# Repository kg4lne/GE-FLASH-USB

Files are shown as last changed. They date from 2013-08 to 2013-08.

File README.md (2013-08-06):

GE-Flash-USB X2212/X2444 EPROM Programmer
=========================================

This archive contains all the CAD and firmware files necessary to build the
GE-Flash-USB EPROM programmer for use with the GE-Flash programming software
by KG4LNE. GE-Flash is a complete solution for programming vintage GE Phoenix,
Delta and Ranger VHF/UHF commercial radios. For more information, please visit
the website at http://www.rtzaudio.com/kg4lne for additional information.

This package includes all PCB CAD files and firmware C source code. All PCB CAD
files are in Cadsoft Eagle v6.4.0 format. The source code for the AT90USB firmware
was developed in Atmel Studio 6.1 and was originally adapted from the USBKEY sample
provided by Atmel. I modified this from a mass storage device into to a simple
read/write USB device. The simple USB device can be accessed on Windows 7/8 via
the built-in generic WinUSB interface that ships with Windows.

You will need to install and configure your GE-Flash-USB programmer device to
communicate with WinUSB just like any other device though. The GE-Flash-USB driver
install and INF files are located on my website and are included in the 
GE-Flash application installer also. Be sure and have the INF and other driver
files on your machine (or install the GE-Flash application first). You can let
Windows search the GE-Flash program files application directory for the INF
file as well.

Note the BOM files for the programmer PCB are located in the project BOM 
subdirectory, here you'll also find an order upload file
"GEF-USB-B_OrderUploadDigiKey.csv" that can be uploaded to Digikey.
Upload the parts order file using the Digikey BOM manager in your account,
this will preload an order with all parts needed to build the PCB. 

Enjoy!

KG4LNE

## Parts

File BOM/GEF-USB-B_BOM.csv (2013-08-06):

Qty | Part References | Value | Package | Mfg Part Num | Mfg Name | VID | Vendor Part Num | Description | XREF
9 | C2, C10, C11, C50, C51, C52, C55, C56, C57 | 0.1uF | C0805 | GCM21BR72A104KA37L | Murata Electronics | DK | 490-4789-1-ND | CAP CER .1UF 100V X7R 0805 | REF24
3 | C9(DNP), C14, C15 | 0.22uF | C0805 | GCM21BR71H224KA37L | Murata Electronics | DK | 490-4970-1-ND | CAP CER .22UF 50V X7R 0805 | REF26
1 | R50 | 0R | R0805 | ERJ-6GEY0R00V | Panasonic - ECG | DK | P0.0ACT-ND | RES 0.0 OHM 1/8W 0805 SMD | REF29
4 | R2, R7, R8, R14 | 1K | R0805 | ERJ-6ENF1001V | Panasonic - ECG | DK | P1.00KCCT-ND | RES 1.00K OHM 1/8W 1% 0805 SMD | REF30
7 | C3, C4, C5, C6, C8, C53, C54 | 1uF | C0805 | GCM21BR71E105KA56L | Murata Electronics | DK | 490-4785-1-ND | CAP CER 1UF 25V X7R 0805 | REF27
1 | R1 | 3.40K | R0805 | ERJ-6ENF3401V | Panasonic - ECG | DK | P3.40KCCT-ND | RES 3.40K OHM 1/8W 1% 0805 SMD | REF31
1 | C7 | 4.7uF | C3528/T | TAJB475K010RNJ | AVX Corporation | DK | 478-3886-1-ND | CAP TANTALUM 4.7UF 10V 10% SMD | REF23
1 | C1 | 4.7uF | C7343/T | TAJD475M035RNJ | AVX Corporation | DK | 478-3934-1-ND | CAP TANTALUM 4.7UF 35V 20% SMD | REF22
1 | Y1 | 8.0 MHZ | HC49UP | ECS-80-18-5PX-TR | ECS Inc | DK | XC1271CT-ND | CRYSTAL 8.00MHZ 18PF SMD | REF17
3 | R3, R6, R51 | 10K | R0805 | ERJ-6ENF1022V | Panasonic - ECG | DK | P10.2KCCT-ND | RES 10.2K OHM 1/8W 1% 0805 SMD | REF32
2 | R10, R11 | 22R | R0805 | ERJ-6ENF22R1V | Panasonic - ECG | DK | P22.1CCT-ND | RES 22.1 OHM 1/8W 1% 0805 SMD | REF33
2 | C12, C13 | 22pF | C0805 | GRM2195C2A220JZ01D | Murata Electronics | DK | 490-1591-1-ND | CAP CER 22PF 100V 5% C0G 0805 | REF25
3 | R4(DNP), R12, R13 | 47K | R0805 | ERJ-6ENF4702V | Panasonic - ECG | DK | P47.0KCCT-ND | RES 47.0K OHM 1/8W 1% 0805 SMD | REF35
2 | RN1, RN2 | 47R | 744-8 | 744C083470JTR | CTS Resistor Products | DK | 744C083470JPCT-ND | RES ARRAY 47 OHM 8TERM 4RES SMD | REF20
1 | RN50 | 100K | 744-8 | 744C083104JPTR | CTS Resistor Products | DK | 744C083104JPCT-ND | RES ARRAY 100KOHM 8TERM 4RES SMD | REF21
2 | R5, R9 | 100K | R0805 | ERJ-6ENF1003V | Panasonic - ECG | DK | P100KCCT-ND | RES 100K OHM 1/8W 1% 0805 SMD | REF36
1 | BOM-PART1 | 151IBK | * | 151IBK | Serpac | DK | SR151-IB-ND | PLASTIC ENCLOSURE 5.62X3.25X1.50 BLACK | REF39
1 | J3 | 182-009-113R531 | NC182M9 | 182-009-113R531 | Norcomp Inc. | DK | 182-09ME-ND | CONN DB9 MALE .318 R/A NICKEL | REF15
1 | BOM-PART2 | 801-93-050-10-001000 | * | 801-93-050-10-001000 | Mill-Max Mfg Corp | DK | ED7150-ND | SIP SOCKET 50 POS STRAIGHT PCB | REF40
1 | J4 | 56579-0576 | 56579-0576 | 56579-0576 | Molex Inc | DK | WM17122CT-ND | CONN RECEPT USB 5POS RT ANG SMD | REF14
1 | JP1 | 961204-6404-AR | JP2Q | 961204-6404-AR | 3M | DK | 3M9458-ND | CONN HEADER VERT DUAL 4POS GOLD | REF42
1 | J2 | 961206-6404-AR | HDR-MA03-2 | 961206-6404-AR | 3M | DK | 3M9459-ND | CONN HEADER VERT DUAL 6POS GOLD | REF43
1 | J5 | 5103309-1 | HDR-5103309-1 | 5103309-1 | Tyco Electronics | DK | A33160-ND | CONN HEADER LOPRO STR 10POS GOLD | REF16
1 | U3 | AT90USB1286-AU | TQFP64A | AT90USB1286-AU | Atmel | DK | AT90USB1286-AURCT-ND | MCU AVR 64K FLASH 16MHZ 64TQFP | REF2
1 | S50(DNP) | B3F-1025 | B3F-10XX-B | B3F-1025 | Omron Electronics Inc | DK | SW794-ND | SWITCH TACT 6MM 260GF H=5.0MM | REF11
2 | S1, S2 | B3U-1000P | B3U-1000P | B3U-1000P | Omron Electronics Inc | DK | SW1020CT-ND | SWITCH TACT SPST W/O GND SMD | REF12
2 | D1, D2 | B140-13-F | SMA | B140-13-F | Diodes Inc | DK | B140-FDICT-ND | DIODE SCHOTTKY 40V 1A SMA | REF38
2 | Q2, Q4 | BC847BMTF | SOT23 | BC847BMTF | Fairchild Semiconductor | DK | BC847BMTFCT-ND | TRANSISTOR NPN 45V 0.1A SOT23 | REF4
1 | L50 | BEAD | L0805 | BLM21PG221SN1D | Murata Electronics | DK | 490-1054-1-ND | FERRITE CHIP 220 OHM 2000MA 0805 | REF28
1 | B1 | DF005S | DF-S | DF005S | Fairchild Semiconductor | DK | DF005SCT-ND | DIODE BRIDGE 50V 1.5A 4-SDIP | REF5
2 | Q1, Q3 | DMP3130L | SOT23 | DMP3130L | Diodes Inc | DK | DMP3130LDICT-ND | MOSFET P-CH 30V 3.5A SOT-23 | REF6
2 | D50, D53 | GREEN | LED3MM | TLHG4405 | Vishay Semiconductor | DK | 751-1101-ND | LED 3MM GREEN 15MCD GAP ON GAP | REF10
1 | U1 | LM340MP-5.0/NOPB | SOT223 | LM340MP-5.0/NOPB | National Semiconductor | DK | LM340MP-5.0/NOPBCT-ND | IC REG LDO 5V 1A SOT223 | REF7
1 | U2 | MAX232ECWE | SO16W | MAX232ECWE+ | Maxim Integrated Products | DK | MAX232ECWE+-ND | IC TXRX RS232 5V ESD-PROT 16SOIC | REF8
1 | F1 | MINISMDC014F-2 | F1812 | MINISMDC014F-2 | Tyco Electronics | DK | MINISMDC014FCT-ND | POLYSWITCH .14A RESET FUSE SMD | REF19
2 | D51, D52 | PGB1010603MR | PGB-0603 | PGB1010603MR | Littelfuse Inc | DK | F2594CT-ND | SUPPRESSOR ESD 24VDC 0603 SMD | REF18
1 | J1 | PJ-102AH/BH | PJ-102XH | PJ-102AH | CUI Inc | DK | CP-102AH-ND | CONN PWR JACK 2.1X5.5MM HIGH CUR | REF13
1 | D54 | RED | LED3MM | TLHR4405 | Vishay Semiconductor | DK | 751-1129-ND | LED 3MM RED 15MCD GAASP ON GAP | REF9
1 | X50 | ZIF28 | ZIF28 | 28-6554-11 | Aries Electronics | DK | A303-ND | 28 PIN ZIF SOCKET GOLD | REF41

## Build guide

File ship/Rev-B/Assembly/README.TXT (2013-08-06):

This directory contains files needed for pick/place assembly and manufacturing.

GEF-USB-B		06/18/2013

GEF-USB-B.cad		GenCad Mount Data
GEF-USB-B.fab		Fabmaster Data
GEF-USB-B.mnt		Generic format Mount X/Y Data
GEF-USB-B.ict		In circuit test net data for electical testing
GEF-USB-B-Top.pdf	PDF top side silk screen image
GEF-USB-B-Bot.pdf	PDF bottom side silk screen image

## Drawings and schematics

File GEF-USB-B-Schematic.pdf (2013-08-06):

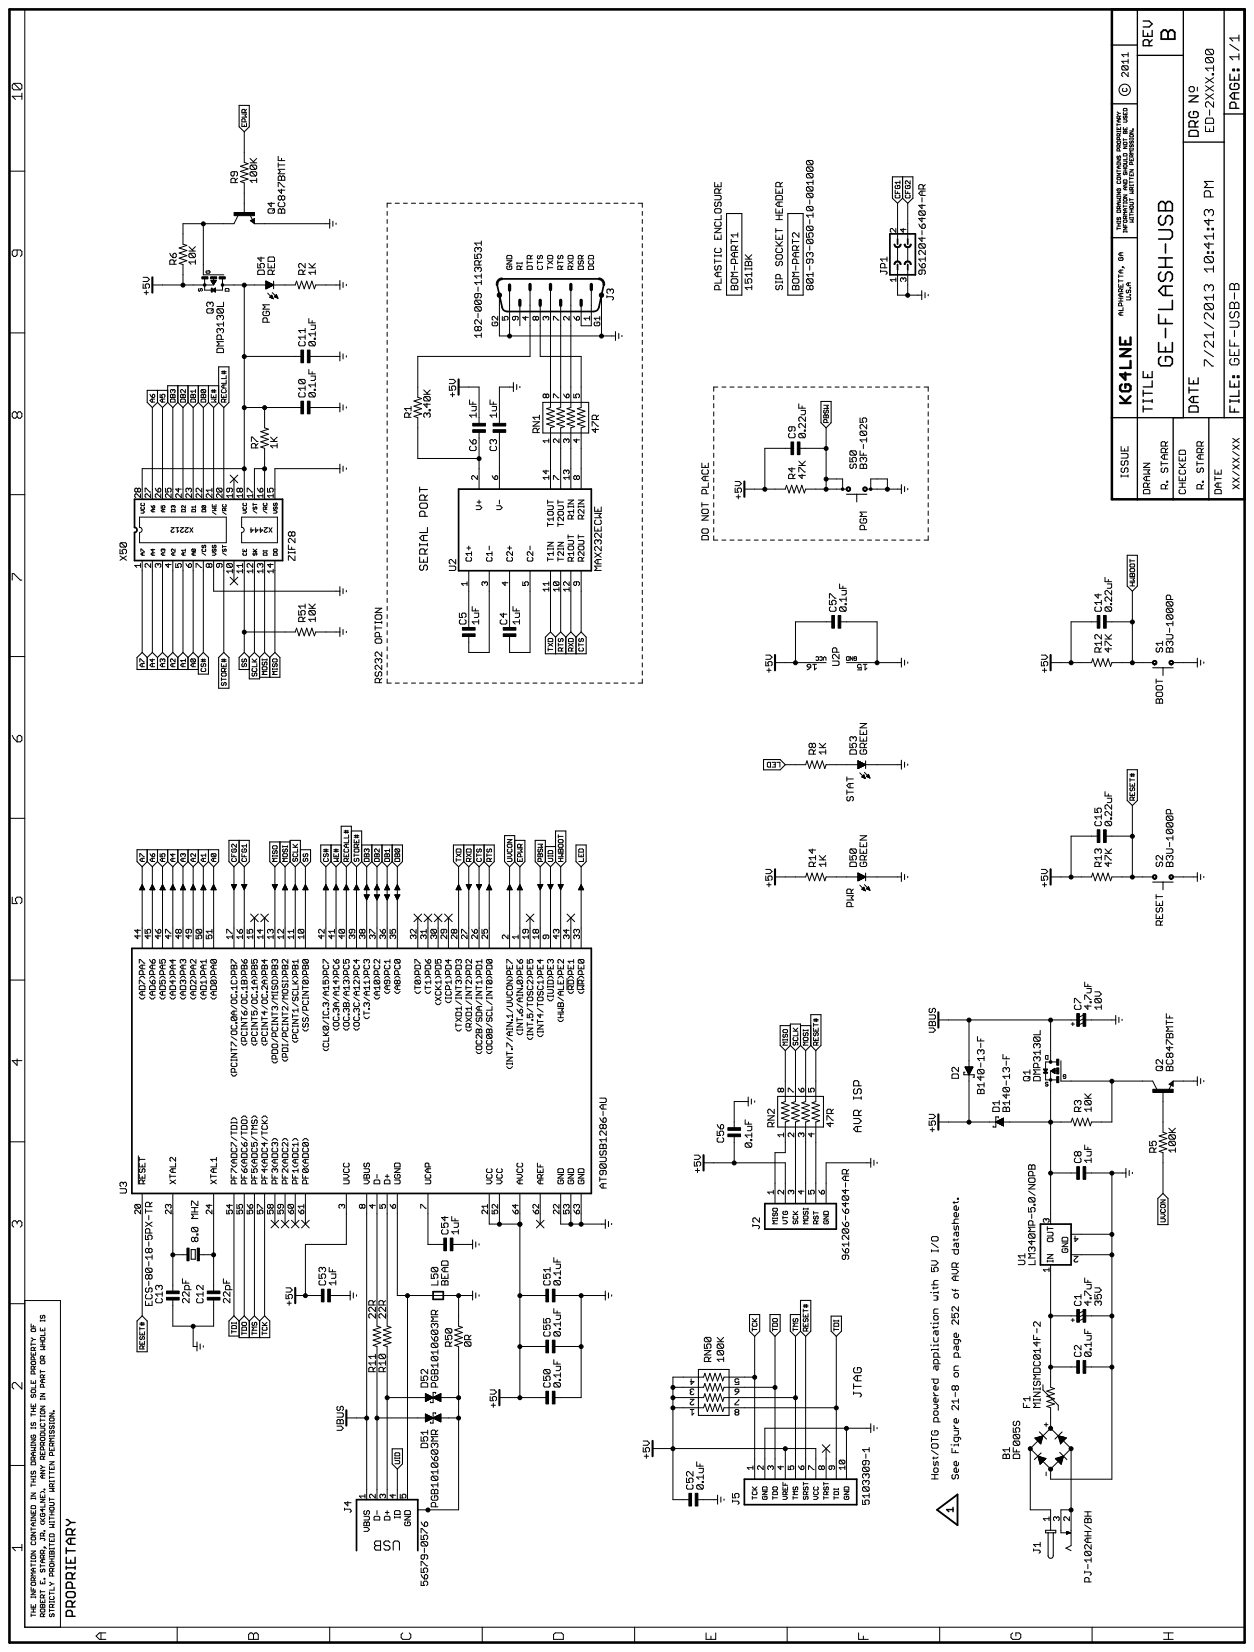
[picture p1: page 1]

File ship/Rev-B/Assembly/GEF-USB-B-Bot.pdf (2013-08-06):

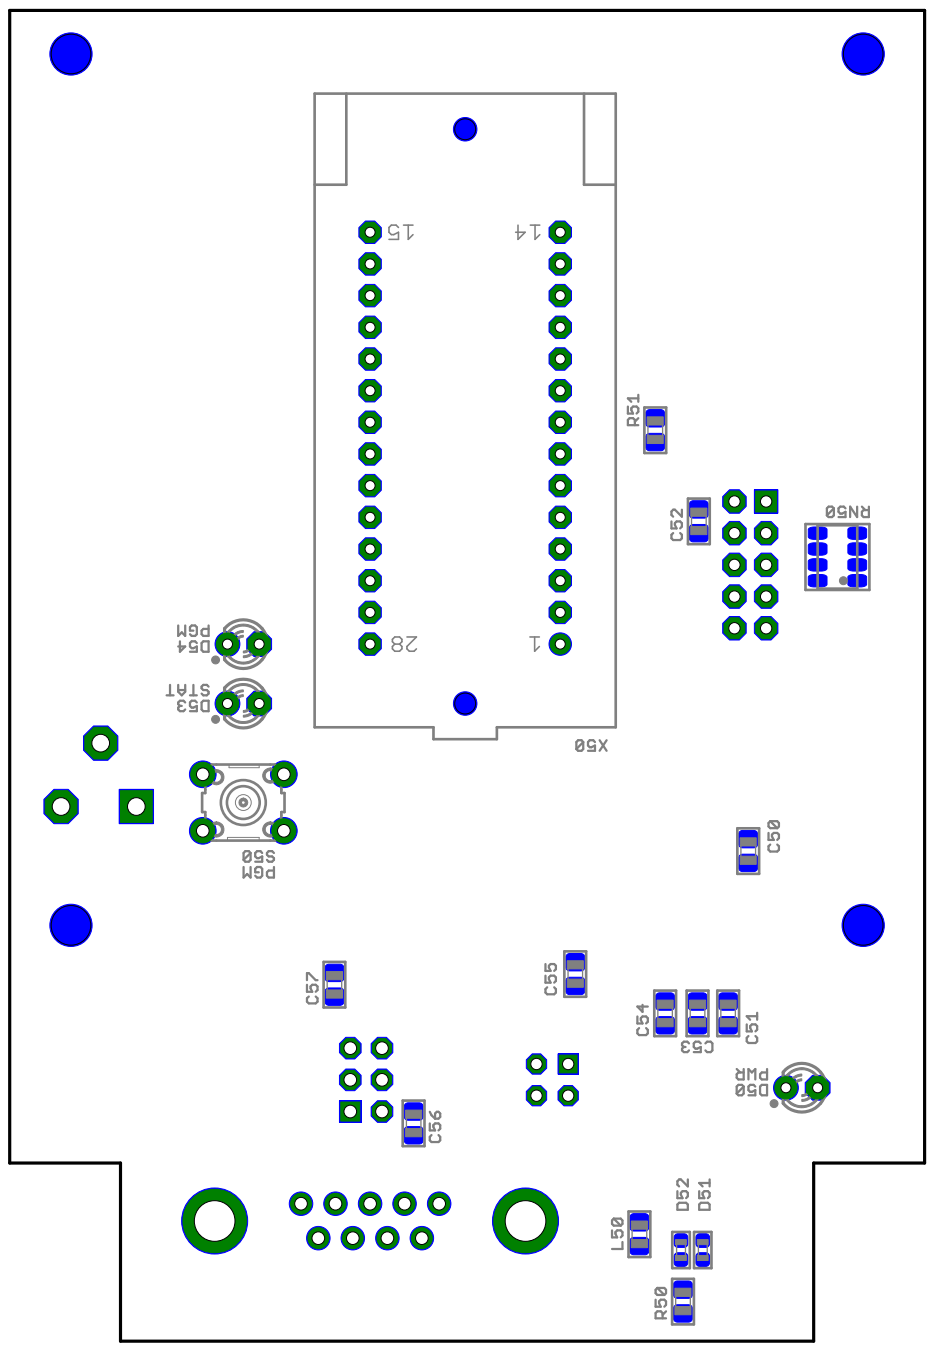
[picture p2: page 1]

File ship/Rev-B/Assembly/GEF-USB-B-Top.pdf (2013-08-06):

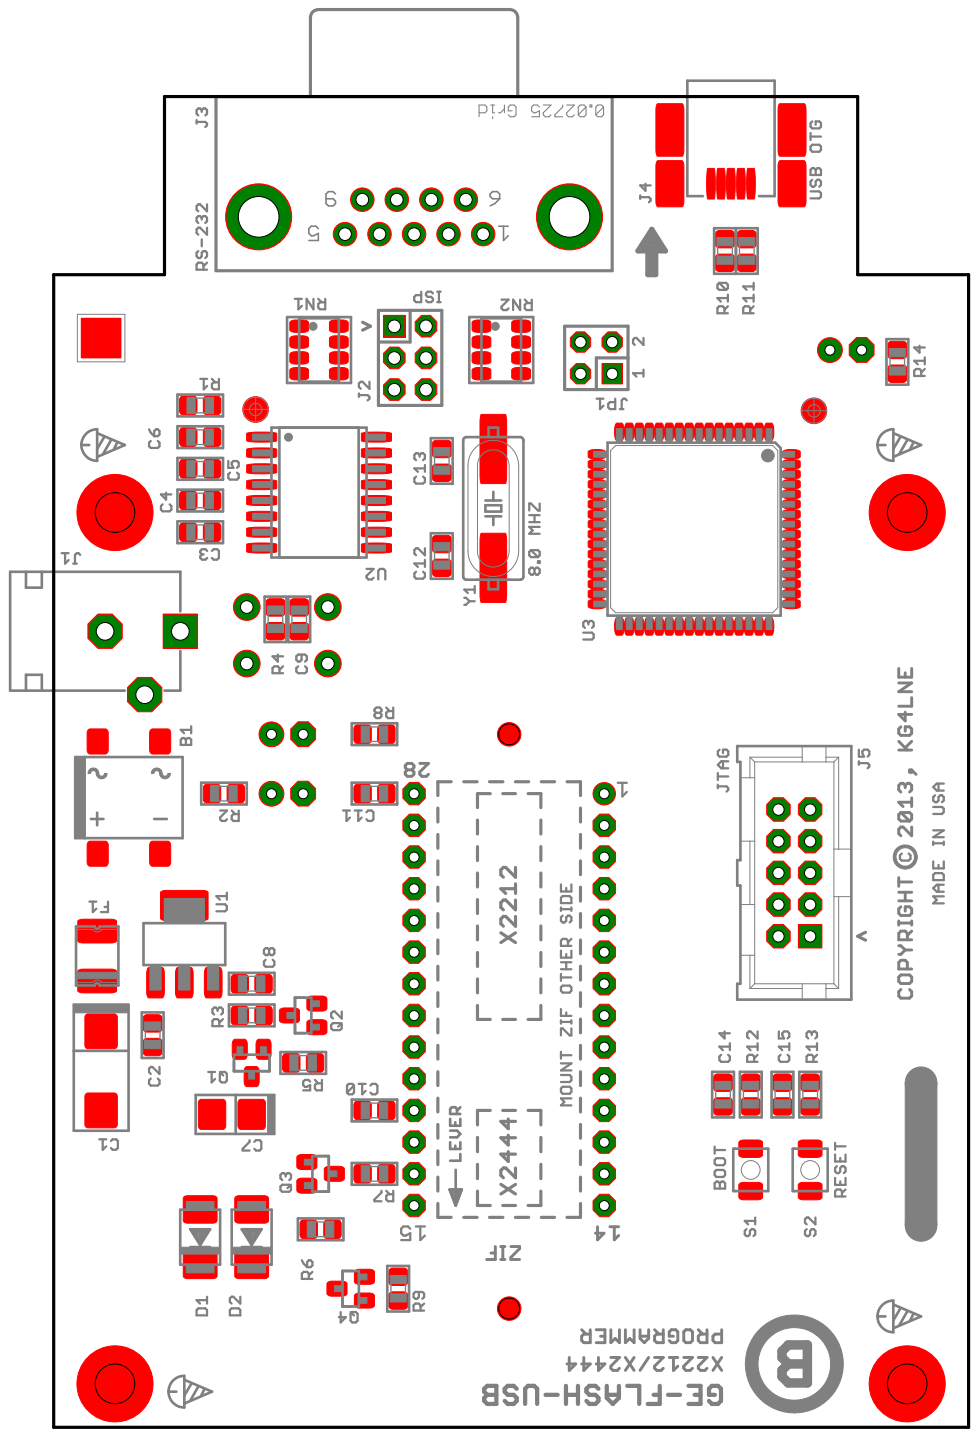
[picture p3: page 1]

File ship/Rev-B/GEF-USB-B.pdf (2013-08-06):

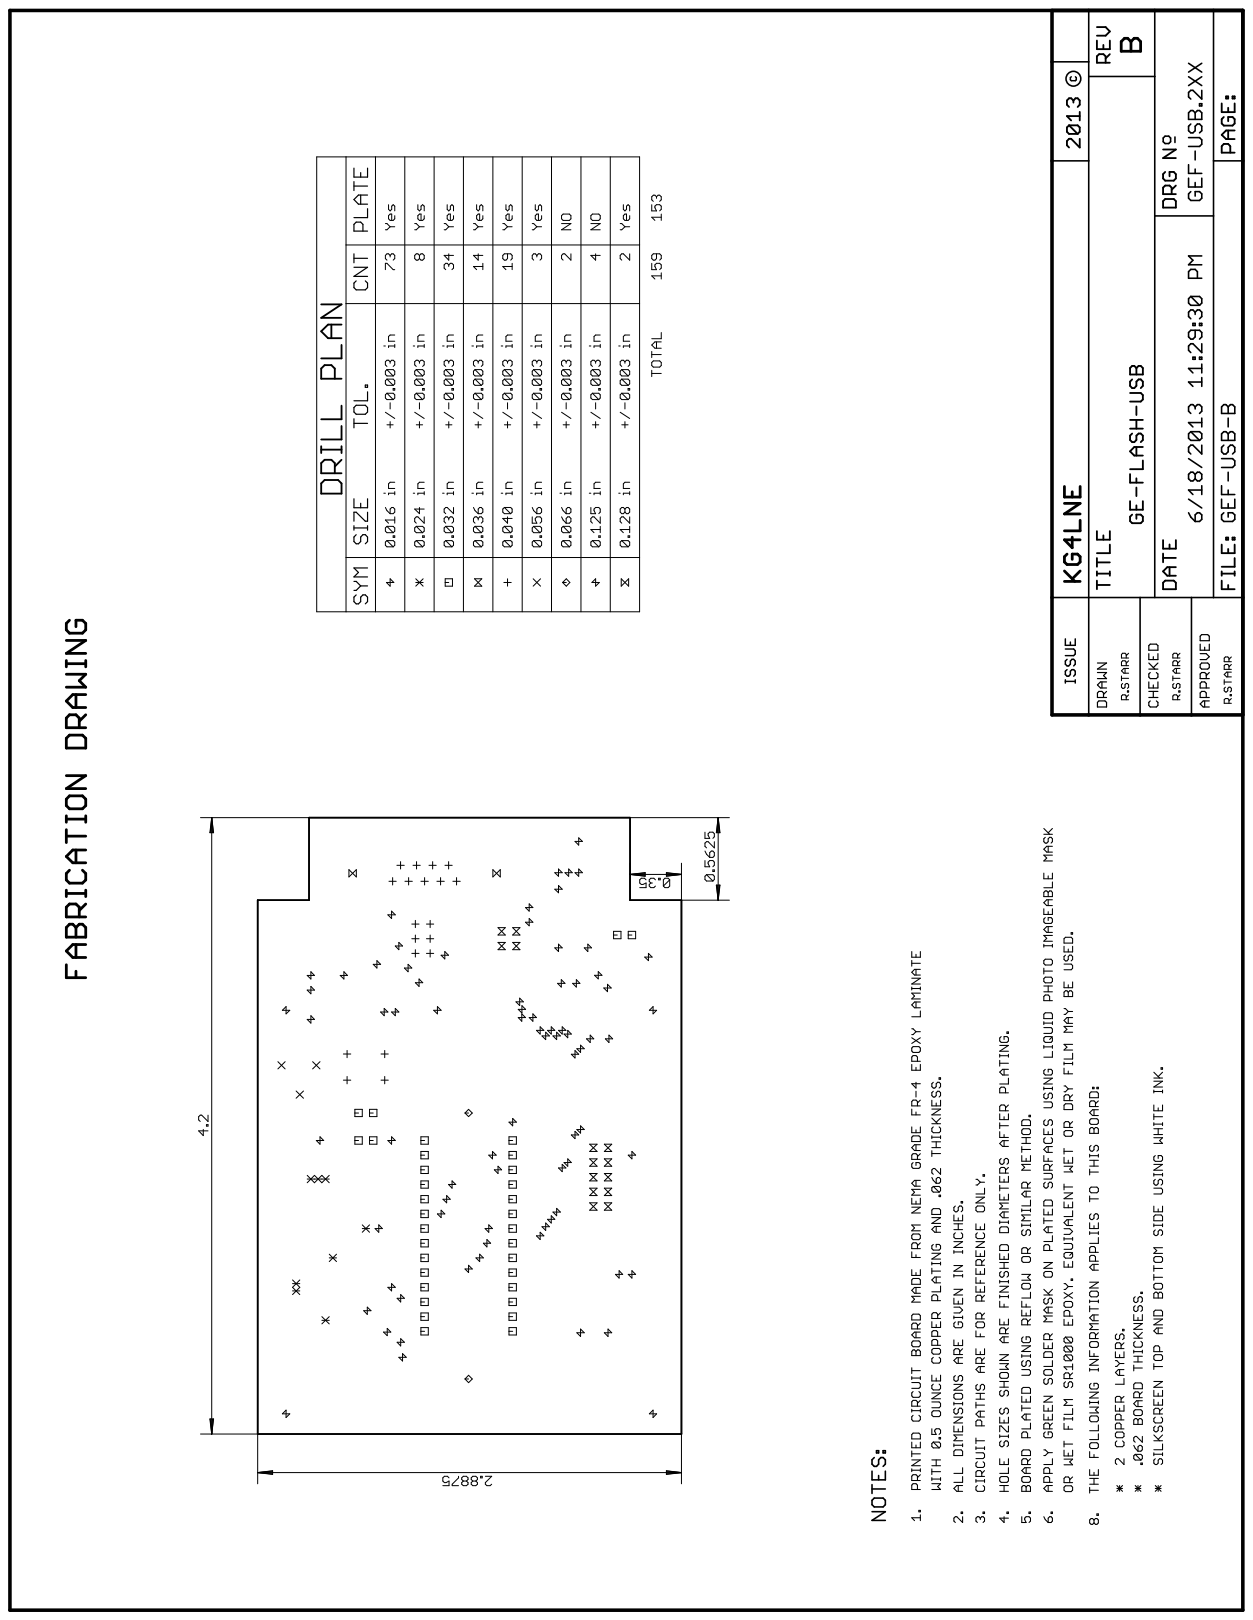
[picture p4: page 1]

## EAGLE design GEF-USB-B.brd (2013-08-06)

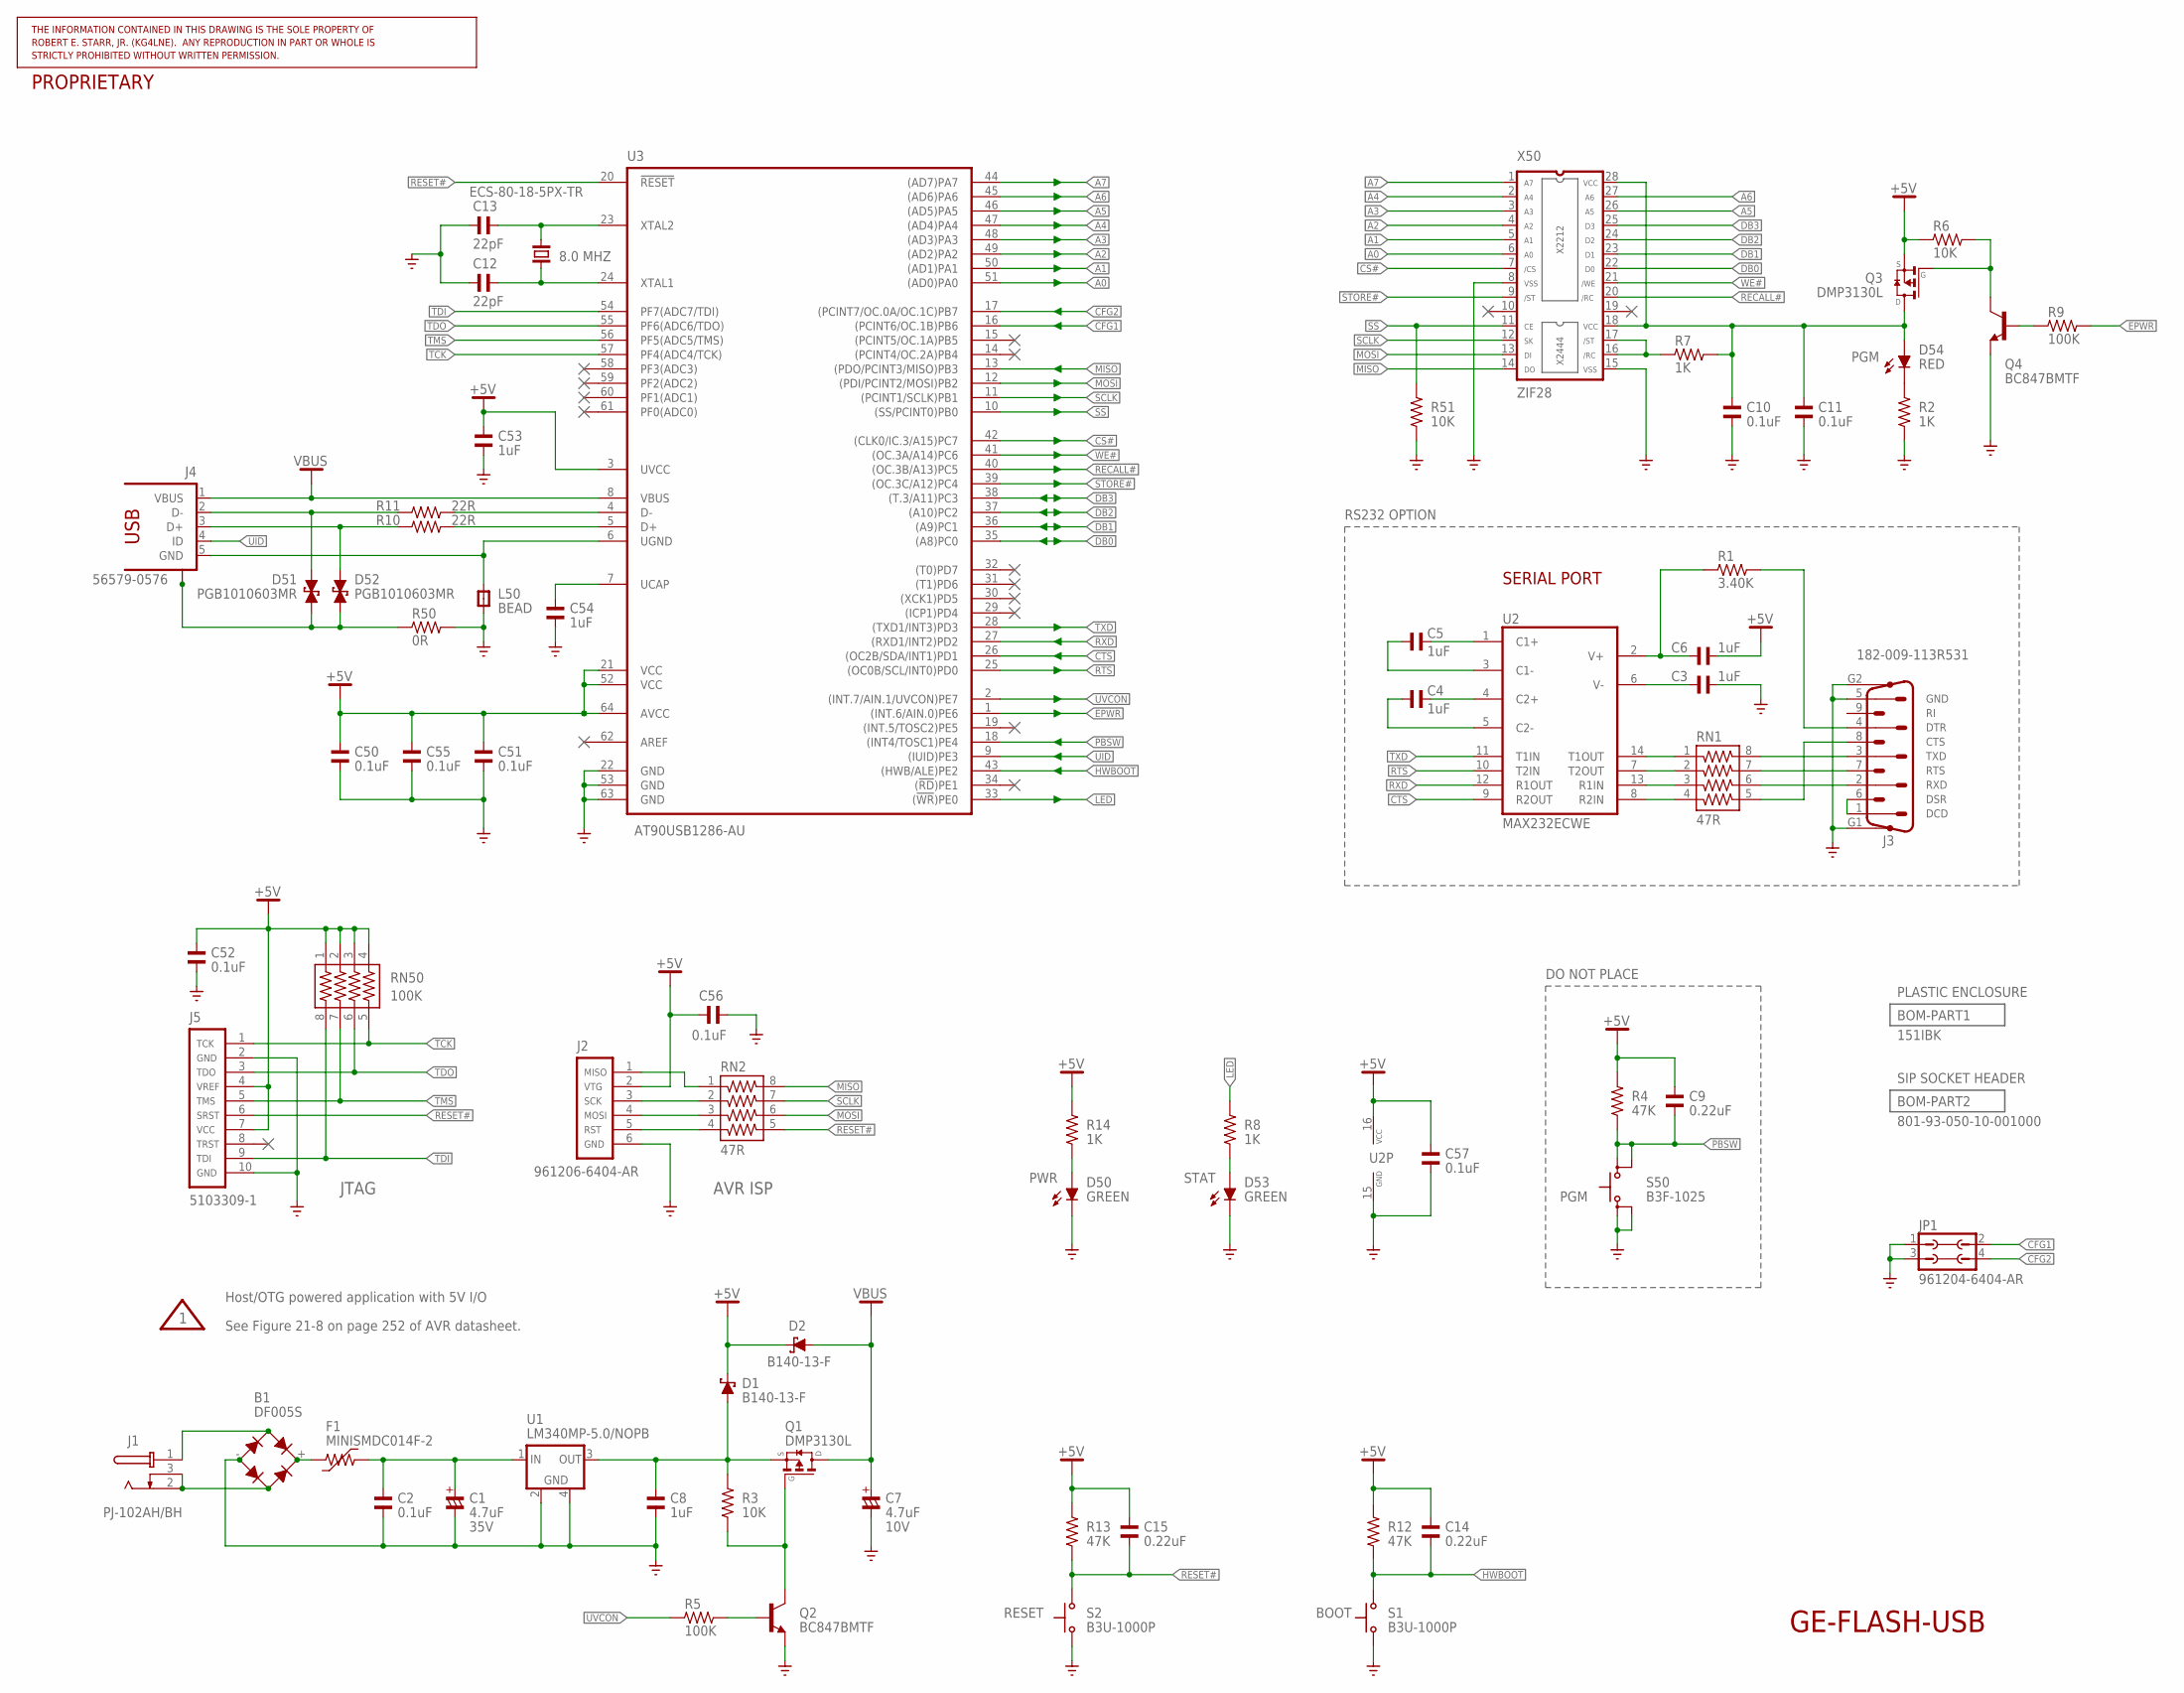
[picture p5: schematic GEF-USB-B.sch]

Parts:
B1: DF005S; DF-S; PARTNO DF005S
C1: 4.7uF; C7343/T; PARTNO TAJD475M035RNJ
C2, C10, C11, C50, C51, C52, C55, C56, C57: 0.1uF; C0805; PARTNO GCM21BR72A104KA37L
C3, C4, C5, C6, C8, C53, C54: 1uF; C0805; PARTNO GCM21BR71E105KA56L
C7: 4.7uF; C3528/T; PARTNO TAJB475K010RNJ
C9, C14, C15: 0.22uF; C0805; PARTNO GCM21BR71H224KA37L
C12, C13: 22pF; C0805; PARTNO GRM2195C2A220JZ01D
D1, D2: B140-13-F; SMA; PARTNO B140-13-F
D50, D53: GREEN; LED3MM; PARTNO TLHG4405
D51, D52: PGB1010603MR; PGB-0603; PARTNO PGB1010603MR
D54: RED; LED3MM; PARTNO TLHR4405
F1: MINISMDC014F-2; F1812; PARTNO MINISMDC014F-2
J1: PJ-102AH/BH; PJ-102XH; PARTNO PJ-102AH
J2: 961206-6404-AR; HDR-MA03-2; PARTNO 961206-6404-AR
J3: 182-009-113R531; NC182M9; PARTNO 182-009-113R531
J4: 56579-0576; PARTNO 56579-0576
J5: 5103309-1; HDR-5103309-1; PARTNO 5103309-1
JP1: 961204-6404-AR; JP2Q; PARTNO 961204-6404-AR
L50: BEAD; L0805; PARTNO BLM21PG221SN1D
Q1, Q3: DMP3130L; SOT23; PARTNO DMP3130L
Q2, Q4: BC847BMTF; SOT23; PARTNO BC847BMTF
R1: 3.40K; R0805; PARTNO ERJ-6ENF3401V
R2, R7, R8, R14: 1K; R0805; PARTNO ERJ-6ENF1001V
R3, R6, R51: 10K; R0805; PARTNO ERJ-6ENF1022V
R4, R12, R13: 47K; R0805; PARTNO ERJ-6ENF4702V
R5, R9: 100K; R0805; PARTNO ERJ-6ENF1003V
R10, R11: 22R; R0805; PARTNO ERJ-6ENF22R1V
R50: 0R; R0805; PARTNO ERJ-6GEY0R00V
RN1, RN2: 47R; 744-8; PARTNO 744C083470JTR
RN50: 100K; 744-8; PARTNO 744C083104JPTR
S1, S2: B3U-1000P; PARTNO B3U-1000P
S50: B3F-1025; B3F-10XX-B; PARTNO B3F-1025
U1: LM340MP-5.0/NOPB; SOT223; PARTNO LM340MP-5.0/NOPB
U2: MAX232ECWE; SO16W; PARTNO MAX232ECWE+
U3: AT90USB1286-AU; TQFP64A; PARTNO AT90USB1286-AU
X50: ZIF28; PARTNO 28-6554-11
Y1: 8.0 MHZ; HC49UP; PARTNO ECS-80-18-5PX-TR

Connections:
+5V: C6.1, C9.2, C14.2, C15.2, C50.1, C51.2, C52.1, C53.2, C55.1, C56.2, C57.1, D1.C, D2.C, J2.2, J5.4, J5.7, Q3.2 (S), R4.2, R6.1, R12.2, R13.2, R14.2, RN50.1, RN50.2, RN50.3, RN50.4, U2.16 (VCC), U3.3 (UVCC), U3.21 (VCC), U3.52 (VCC), U3.64 (AVCC)
A0: U3.51 ((AD0)PA0), X50.6
A1: U3.50 ((AD1)PA1), X50.5
A2: U3.49 ((AD2)PA2), X50.4
A3: U3.48 ((AD3)PA3), X50.3
A4: U3.47 ((AD4)PA4), X50.2
A5: U3.46 ((AD5)PA5), X50.26
A6: U3.45 ((AD6)PA6), X50.27
A7: U3.44 ((AD7)PA7), X50.1
CFG1: JP1.2, U3.16 ((PCINT6/OC.1B)PB6)
CFG2: JP1.4, U3.17 ((PCINT7/OC.0A/OC.1C)PB7)
CS#: U3.42 ((CLK0/IC.3/A15)PC7), X50.7
CTS: U2.9 (R2OUT), U3.26 ((OC2B/SDA/INT1)PD1)
DB0: U3.35 ((A8)PC0), X50.22
DB1: U3.36 ((A9)PC1), X50.23
DB2: U3.37 ((A10)PC2), X50.24
DB3: U3.38 ((T.3/A11)PC3), X50.25
EPWR: R9.2, U3.1 ((INT.6/AIN.0)PE6)
GND: B1.-, C1.-, C2.1, C3.1, C7.-, C8.2, C10.1, C11.1, C12.1, C13.1, C50.2, C51.1, C52.2, C53.1, C54.1, C55.2, C56.1, C57.2, D50.K (C), D53.K (C), J2.6, J3.5, J3.G1, J3.G2, J5.2, J5.10, JP1.1, JP1.3, L50.1, Q2.2 (E), Q4.2 (E), R2.1, R50.2, R51.1, S1.1, S2.1, S50.3, S50.4 (P1), U1.2 (GND), U1.4 (GND1), U2.15 (GND), U3.22 (GND), U3.53 (GND), U3.63 (GND), X50.8, X50.15
HWBOOT: C14.1, R12.1, S1.2 (S), U3.43 ((HWB/ALE)PE2)
LED: R8.2, U3.33 ((!WR!)PE0)
MISO: RN2.8, U3.13 ((PDO/PCINT3/MISO)PB3), X50.14
MOSI: RN2.6, U3.12 ((PDI/PCINT2/MOSI)PB2), X50.13
unnamed: J2.5, RN2.4
unnamed: B1.AC2 (A2), J1.2 (S), J1.3 (SS)
unnamed: R10.2, U3.5 (D+)
unnamed: D52.2, J4.3 (D+), R10.1
unnamed: R11.2, U3.4 (D-)
unnamed: D51.2, J4.2 (D-), R11.1
unnamed: C54.2, U3.7 (UCAP)
unnamed: D50.A, R14.1
unnamed: D51.1, D52.1, J4.S1, J4.S2, J4.S3, J4.S4, R50.1
unnamed: D53.A, R8.1
unnamed: Q1.1 (G), Q2.3 (C), R3.1
unnamed: Q2.1 (B), R5.2
unnamed: Q3.1 (G), Q4.3 (C), R6.2
unnamed: C10.2, C11.2, D54.A, Q3.3 (D), R7.2, X50.18, X50.28
unnamed: D54.K (C), R2.2
unnamed: J4.5 (GND), L50.2, U3.6 (UGND)
unnamed: J3.1, J3.6
unnamed: C1.+, C2.2, F1.2, U1.1 (IN)
unnamed: C8.1, D1.A, Q1.2 (S), R3.2, U1.3 (OUT)
unnamed: J3.2, RN1.6
unnamed: B1.+, F1.1
unnamed: B1.AC1 (A1), J1.1 (T)
unnamed: Q4.1 (B), R9.1
unnamed: C12.2, U3.24 (XTAL1), Y1.1
unnamed: J3.7, RN1.7
unnamed: C3.2, U2.6 (V-)
unnamed: C6.2, R1.1, U2.2 (V+)
unnamed: C13.2, U3.23 (XTAL2), Y1.2
unnamed: C4.1, U2.4 (C2+)
unnamed: C5.1, U2.1 (C1+)
unnamed: C4.2, U2.5 (C2-)
unnamed: C5.2, U2.3 (C1-)
unnamed: J3.8, RN1.5
unnamed: J3.3, RN1.8
unnamed: RN1.3, U2.13 (R1IN)
unnamed: RN1.1, U2.14 (T1OUT)
unnamed: RN1.4, U2.8 (R2IN)
unnamed: J3.4, R1.2
unnamed: RN1.2, U2.7 (T2OUT)
unnamed: J2.1, RN2.1
unnamed: J2.3, RN2.2
unnamed: J2.4, RN2.3
PBSW: C9.1, R4.1, S50.1 (S), S50.2 (S1), U3.18 ((INT4/TOSC1)PE4)
PU2: R7.1, X50.16, X50.17
RECALL#: U3.40 ((OC.3B/A13)PC5), X50.20
RESET#: C15.1, J5.6, R13.1, RN2.5, S2.2 (S), U3.20 (!RESET!)
RTS: U2.10 (T2IN), U3.25 ((OC0B/SCL/INT0)PD0)
RXD: U2.12 (R1OUT), U3.27 ((RXD1/INT2)PD2)
SCLK: RN2.7, U3.11 ((PCINT1/SCLK)PB1), X50.12
SS: R51.2, U3.10 ((SS/PCINT0)PB0), X50.11
STORE#: U3.39 ((OC.3C/A12)PC4), X50.9
TCK: J5.1, RN50.5, U3.57 (PF4(ADC4/TCK))
TDI: J5.9, RN50.8, U3.54 (PF7(ADC7/TDI))
TDO: J5.3, RN50.6, U3.55 (PF6(ADC6/TDO))
TMS: J5.5, RN50.7, U3.56 (PF5(ADC5/TMS))
TXD: U2.11 (T1IN), U3.28 ((TXD1/INT3)PD3)
UID: J4.4 (ID), U3.9 ((IUID)PE3)
UVCON: R5.1, U3.2 ((INT.7/AIN.1/UVCON)PE7)
VBUS: C7.+, D2.A, J4.1 (VBUS), Q1.3 (D), U3.8 (VBUS)
WE#: U3.41 ((OC.3A/A14)PC6), X50.21

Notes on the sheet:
AVR ISP
JTAG
See Figure 21-8 on page 252 of AVR datasheet.
Host/OTG powered application with 5V I/O
VCC
/WE
/ST
/RC
/CS
VSS
X2444
X2212
SERIAL PORT
DCD
DSR
RXD
RTS
TXD
CTS
DTR
GND
GE-FLASH-USB
DO NOT PLACE
RS232 OPTION

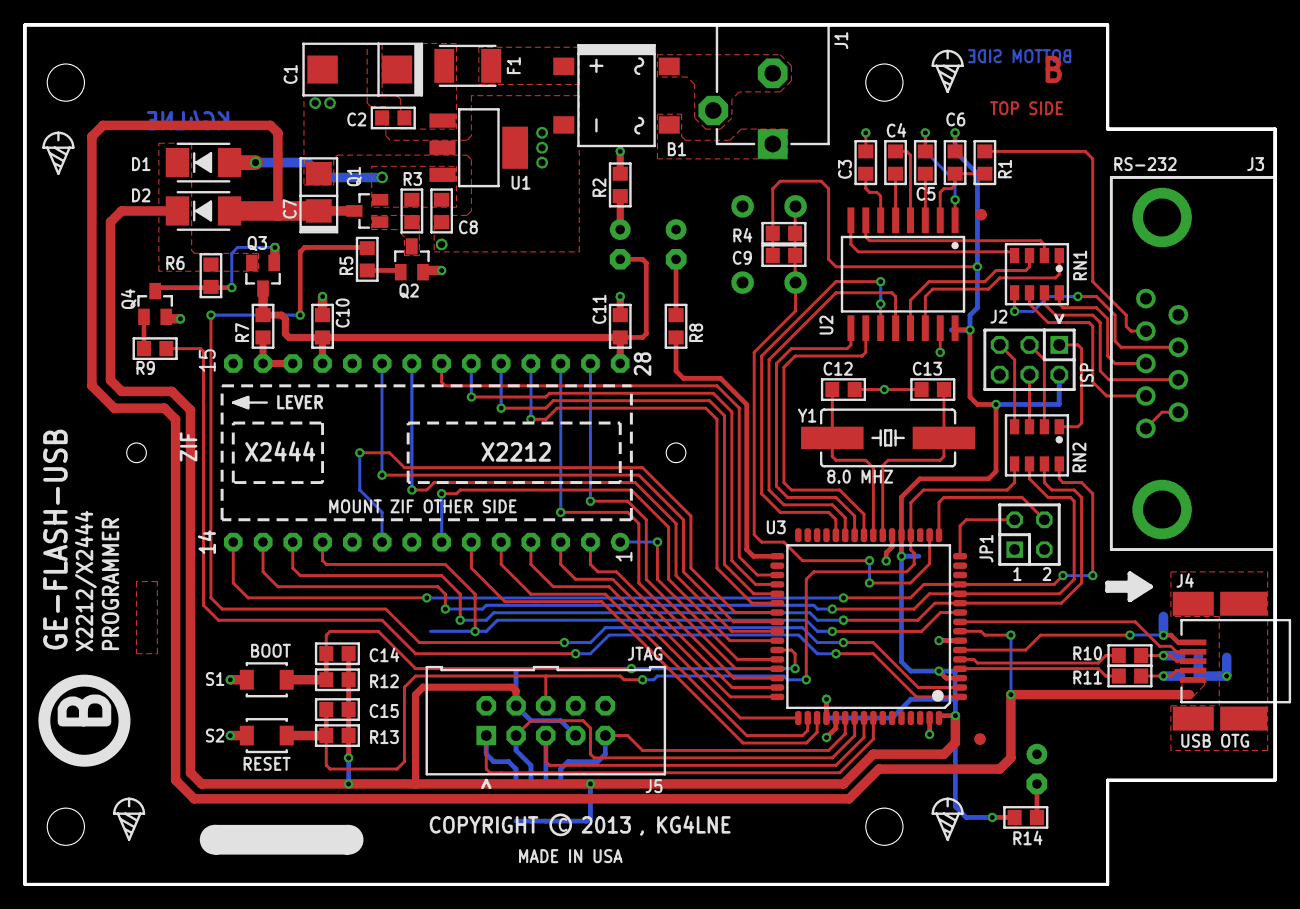
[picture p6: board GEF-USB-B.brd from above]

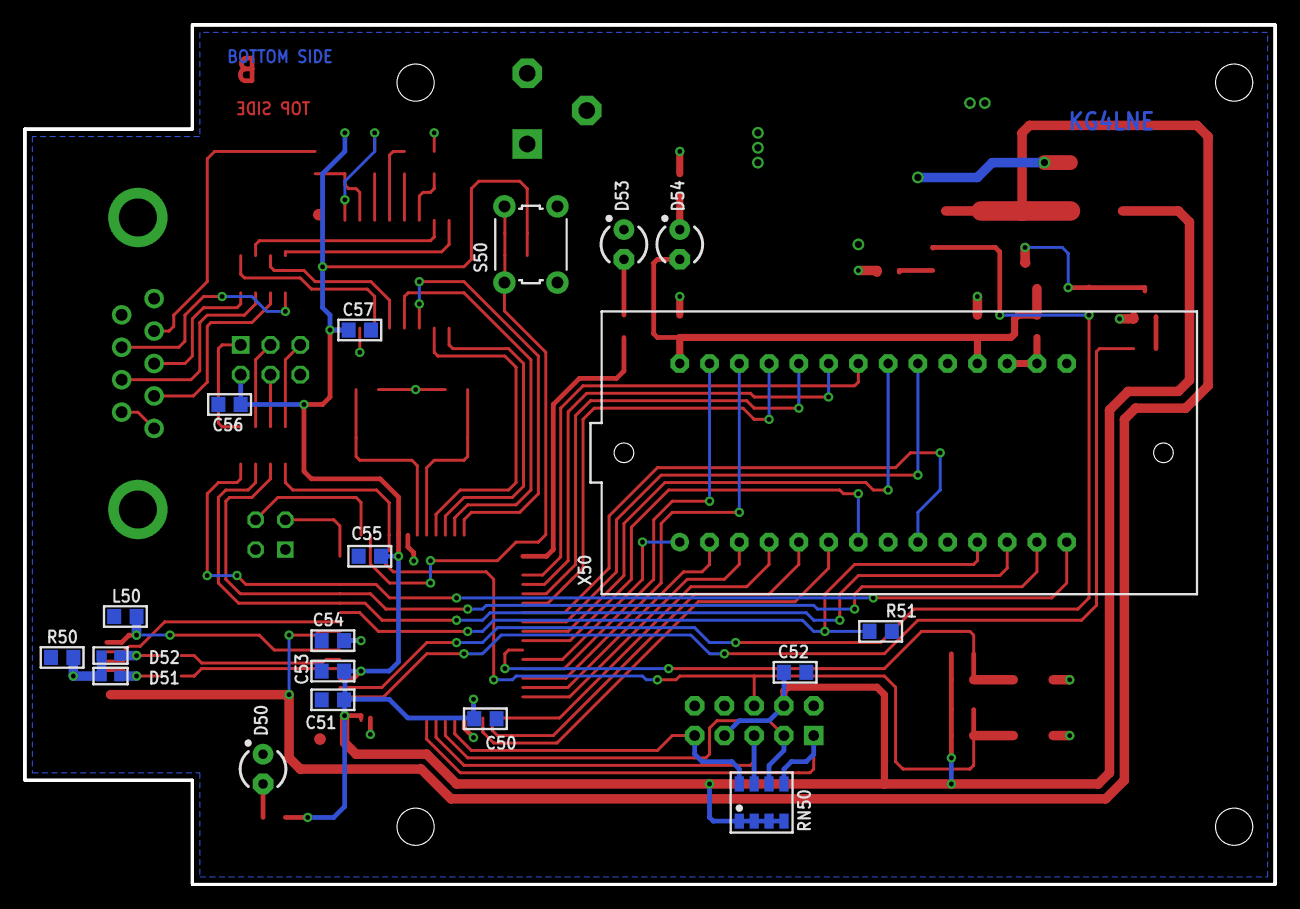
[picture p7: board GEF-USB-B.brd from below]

Board: 2 copper layers, 106.7 x 73.3 mm, 86 parts (19 on the bottom side), 83 nets.

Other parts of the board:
FABFRAME1: FAB_FRAME_ANSI-A
FABFRAME2: FAB_DOCFIELD_GENERIC
FEAT1, FEAT3, FEAT11, FEAT12: ICON_SCREW-S
FEAT2: PCBFEAT-MREV-076
FEAT4, FEAT9: G10
FEAT5, FEAT10: ICON_PIN1_A
FEAT6: ICON_ARROW-S
FEAT7: PCBFEAT-DATECODE-050R
FEAT8: PCBFEAT-REV-150
FEAT13: PCBFEAT-COPYRIGHT-050
FEAT14: FIELD_SCRIBBLE-1

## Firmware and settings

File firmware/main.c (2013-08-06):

/*This file is prepared for Doxygen automatic documentation generation.*/
//! \file *********************************************************************
//!
//! \brief Main for USB application.
//!
//! - Compiler:           IAR EWAVR and GNU GCC for AVR
//! - Supported devices:  AT90USB1287, AT90USB1286, AT90USB647, AT90USB646
//!
//! \author               Atmel Corporation: http://www.atmel.com \n
//!                       Support and FAQ: http://support.atmel.no/
//!
//! ***************************************************************************
//!
//! @mainpage AT90USBxxx USB Mass storage
//!
//! @section intro License
//! Use of this program is subject to Atmel's End User License Agreement.
//!
//! Please read file  \ref lic_page for copyright notice.
//!
//! @section install Description
//! This embedded application source code illustrates how to implement a USB mass storage application
//! over the AT90USBxxx controller.
//!
//! @section sample About the sample application
//! By default the sample code is delivered configured for STK525, but
//! this sample application can be configured for both STK525 or AT90USBKey hardware, see #TARGET_BOARD
//! define value in config.h file.
//!
//!
//! @section Revision Revision
//!
//! @par V2.0.4
//!
//! USB Device Stack :
//! - Class MSC :
//!   - Improve MSC compliance
//!   - Add MSC compliance for Linux 2.4 kernel
//!
//! @par V2.0.3
//!
//! USB Device Stack :
//! - Improve USB device detach behavior in mode self power
//! - Fix bug about back drive voltage on D+ after VBus disconnect (USB Certification)
//! - Remove VBus interrupt (bug IT VBUS, see errata) and manage VBus state by pooling
//! - Fix bug during attach (the interrupt must be disable during attach to don't freeze clock)
//! - Class MSC :
//!   - Add write Protect Management under MAC OS
//!   - Fix bug in sense command to support Vista and Windows Seven
//!
//! @par V2.0.2
//!
//! USB Stack :
//! - Improve USB protocol for USB chap9 and MSC compliance
//!
//! @par V2.0.1
//!
//! USB Stack:
//! - Improve USB protocol for USB chap9 and MSC compliance
//! - Move VBus interrupt to VBus pooling
//! - Fix USB constant about Device Status
//! - Add three possibilities for SN on USB : No SN, Constant SN, Unique SN
//! - clean stack constant
//! - Fix inquiry command
//! - clean and fix specific request
//!
//! DataFlash driver:
//! - Add USB Write Protection management on DataFlash
//! - Fix error on DataFlash I/O initialization
//!
//! New watchdog driver to control the specific sequence timing
//!
//! @par V2.0.0 and before
//!
//! First releases
//!
//! @section src_code About the source code
//! This source code is usable with the following compilers:
//! - IAR Embedded Workbench (5.11A and higher)
//! - AVRGCC (WinAVR 20080411 and higher).
//!
//! Support for other compilers may required modifications or attention for:
//! - compiler.h file 
//! - special registers declaration file
//! - interrupt subroutines declarations
//!
//! @section arch Architecture
//! As illustrated in the figure bellow, the application entry point is located is the main.c file.
//! The main function first performs the initialization of a scheduler module and then runs it in an infinite loop.
//! The scheduler is a simple infinite loop calling all its tasks defined in the conf_scheduler.h file.
//! No real time schedule is performed, when a task ends, the scheduler calls the next task defined in
//! the configuration file (conf_scheduler.h).
//!
//! The sample dual role application is based on two different tasks:
//! - The usb_task  (usb_task.c associated source file), is the task performing the USB low level
//! enumeration process in device mode.
//! - The storage task performs SCSI bulk only protocol decoding and performs flash memory access.
//!
//! \image html arch_full.gif
//!
//! ***************************************************************************

/* Copyright (c) 2009 Atmel Corporation. All rights reserved.
 *
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
 * 3. The name of Atmel may not be used to endorse or promote products derived
 * from this software without specific prior written permission.
 *
 * 4. This software may only be redistributed and used in connection with an Atmel
 * AVR product.
 *
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
SCLAIMED. IN NO EVENT SHALL ATMEL BE LIABLE FOR ANY DIRECT,
 * INDIRECT, INCIDENTAL, SPECIAL, EXEMPLARY, OR CONSEQUENTIAL DAMAGES
 * (INCLUDING, BUT NOT LIMITED TO, PROCUREMENT OF SUBSTITUTE GOODS OR SERVICES;
 * LOSS OF USE, DATA, OR PROFITS; OR BUSINESS INTERRUPTION) HOWEVER CAUSED AND
 * ON ANY THEORY OF LIABILITY, WHETHER IN CONTRACT, STRICT LIABILITY, OR TORT
 * (INCLUDING NEGLIGENCE OR OTHERWISE) ARISING IN ANY WAY OUT OF THE USE OF
 * THIS SOFTWARE, EVEN IF ADVISED OF THE POSSIBILITY OF SUCH DAMAGE.
 */
 
//_____  I N C L U D E S ___________________________________________________

#include "config.h"
#include "scheduler.h"
#include "lib_mcu/wdt/wdt_drv.h"
#include "lib_mcu/power/power_drv.h"

//_____ M A C R O S ________________________________________________________

//_____ D E F I N I T I O N S ______________________________________________

int main(void)
{
    wdtdrv_disable();
    //Clear_prescaler();
    clock_prescale_set(clock_div_1);   
    scheduler();
    return 0;
}

//! \name Procedure to speed up the startup code
//! This one increment the CPU clock before RAM initialisation
//! @{
#ifdef  __GNUC__
// Locate low level init function before RAM init (init3 section)
// and remove std prologue/epilogue
char __low_level_init(void) __attribute__ ((section (".init3"),naked));
#endif

#ifdef __cplusplus
extern "C" {
#endif
char __low_level_init()
{
  //Clear_prescaler();
	clock_prescale_set(clock_div_1);  
  return 1;
}
#ifdef __cplusplus
}
#endif
//! @}

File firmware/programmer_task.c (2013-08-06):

/*
 * GE-Flash USB Programmer
 *
 */

//_____  I N C L U D E S ___________________________________________________

#include "config.h"
#include "conf_usb.h"
#include "spi_drv.h"
#include "async.h"
#include "rs232_task.h"
#include "programmer_task.h"
#include "lib_mcu/usb/usb_drv.h"
#include "usb_descriptors.h"
#include "usb_standard_request.h"
#include "usb_specific_request.h"
#include "usb_ge_flash.h"

#include <util/delay.h>
#include <util/crc16.h>

//_____ D E C L A R A T I O N S ____________________________________________

void usb_eprom_cbw(void);
void usb_eprom_csw(void);
Bool decode_command();

static int x2444_command(uint8_t cmd);
static uint8_t reverse8(uint8_t a);

#define x2444_store()               x2444_command(0x81)
#define x2444_recall()              x2444_command(0x85)
#define x2444_enable_writelatch()   x2444_command(0x84)
#define x2444_disable_writelatch()  x2444_command(0x80)

/* Global Data */

uint8_t     g_buf[BANKSIZE];    /* EPROM data cache buffer */
uint8_t     g_dir;
uint8_t     g_status;
uint8_t     g_data;
uint8_t     g_command;
uint8_t     g_devtype = GEFU_EPROM_TYPE_X2212;
uint16_t    g_address = 0x00;   /* Current read/write address  */

/* External Data */

extern U8 endpoint_status[MAX_EP_NB];

//! This function increments the cpt_sof counter each times
//! the USB Start Of Frame interrupt subroutine is executed (1ms)
//! Usefull to manage time delays
//!

volatile U8 cpt_sof;

void sof_action()
{
   cpt_sof++;
}

/************************************************************************
 * 
 ************************************************************************/

void programmer_task_init(void)
{
    /* Initialize I/O ports */
    io_init();

    Usb_enable_sof_interrupt();
}

/************************************************************************
 * 
 ************************************************************************/

//static U16 g_wEpromBytes = 0;

void programmer_task(void)
{
    static unsigned int cnt;

    if (++cnt >= 60000)
    {
        cnt = 0;
        PORTE ^= _BV(B_LED);
    }

    if (Is_device_enumerated())
    {
        Usb_select_endpoint(EP_MS_OUT);

        if (Is_usb_receive_out())
        {
            usb_eprom_cbw();
            usb_eprom_csw();
        }
    }
}

/************************************************************************
 * USB Command Block Wrapper (CBW) management
 ************************************************************************/

void usb_eprom_cbw(void)
{
    Usb_select_endpoint(EP_MS_OUT);

    /* Read the eprom type ID and command */
    g_command = Usb_read_byte();
    g_status  = Usb_read_byte();
    g_dir     = Usb_read_byte();
    g_data    = Usb_read_byte();

    // Read the 16-bit address
    LSB(g_address) = Usb_read_byte();
    MSB(g_address) = Usb_read_byte();

    /* Set the direction flag */
    if (g_dir != 0x00)
        Usb_set_ms_data_direction_in();
    else
        Usb_set_ms_data_direction_out();

    Usb_ack_receive_out();

    if (Is_usb_ms_data_direction_in())
    {
        Usb_select_endpoint(EP_MS_IN);
    }

    if (decode_command() != TRUE)
    {
        U8 ep;
        Usb_enable_stall_handshake();
        if (Is_usb_ms_data_direction_in())
            ep = (EP_MS_IN & MSK_EP_DIR);
        else
            ep = (EP_MS_OUT & MSK_EP_DIR);
        endpoint_status[ep] = 0x01;
    }
}

/************************************************************************
 * USB Command Status Wrapper (CSW) management
 ************************************************************************/

void usb_eprom_csw(void)
{
    Usb_select_endpoint(EP_MS_IN);
    while (Is_usb_endpoint_stall_requested())
    {
        Usb_select_endpoint(EP_CONTROL);
        if (Is_usb_receive_setup())
        { usb_process_request(); }
        Usb_select_endpoint(EP_MS_IN);
    }

    Usb_select_endpoint(EP_MS_OUT);
    while (Is_usb_endpoint_stall_requested())
    {
        Usb_select_endpoint(EP_CONTROL);
        if (Is_usb_receive_setup())
        { usb_process_request(); }
        Usb_select_endpoint(EP_MS_OUT);
    }

    Usb_select_endpoint(EP_MS_IN);
    while(!Is_usb_write_enabled())
    {
        if(!Is_usb_endpoint_enabled())
            return; // USB Reset
    }

    // Send back the response packet
    Usb_write_byte(g_command);
    Usb_write_byte(g_status);
    Usb_write_byte(g_dir);
    Usb_write_byte(g_data);
    Usb_write_byte(LSB(g_address));
    Usb_write_byte(MSB(g_address));

    Usb_send_in();
}

/************************************************************************
 * Decode the received command and process it
 ************************************************************************/

Bool decode_command()
{
    Bool result = TRUE;
    int i;

    g_status = 0x00;

    switch(g_command)
    {
        // Return the current EPROM type
        case GEFU_CMD_GET_EPROM_TYPE:
            g_data = g_devtype;
            break;

        // Set the EPROM type X2212 or X2444
        case GEFU_CMD_SET_EPROM_TYPE:
            g_devtype = g_data;
            break;

        // Store EPROM data from memory buffer to EPROM
        case GEFU_CMD_STORE:
            PORTE &= ~(_BV(B_LED));
            if (g_devtype == GEFU_EPROM_TYPE_X2444)
                x2444_write(g_buf);
            else
                x2212_write(g_buf);
            break;

        // Recall EPROM data to in memory buffer
        case GEFU_CMD_RECALL:
            PORTE &= ~(_BV(B_LED));
            if (g_devtype == GEFU_EPROM_TYPE_X2444)
                x2444_read(g_buf);
            else
                x2212_read(g_buf);
            break;

        // Read data at address
        case GEFU_CMD_READ_BYTE:
            if (g_address >= BANKSIZE)
            {
                g_status = 0x80;
                break;
            }
            g_data = g_buf[g_address];
            break;

        // Write data at address
        case GEFU_CMD_WRITE_BYTE:
            if (g_address >= BANKSIZE)
            {
                g_status = 0x80;
                break;
            }
            g_buf[g_address] = g_data;
            break;

        // Reset the GE-Flash USB programmer
        case GEFU_CMD_RESET:
            for (i=0; i<BANKSIZE; i++)
                g_buf[i] = 0;
            break;

        default:
            result = FALSE;
            break;
    }

    return result;
}

/************************************************************************
 * X2212 256-Byte Block Read
 ************************************************************************/
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

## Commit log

2013-08-06 Initial Release
    [GEF-USB-B.brd, GEF-USB-B.sch, GEF-USB-B_BOM.csv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]
2014-03-02 BOM updates
    [GEF-USB-B_OrderUploadDigiKey.csv]

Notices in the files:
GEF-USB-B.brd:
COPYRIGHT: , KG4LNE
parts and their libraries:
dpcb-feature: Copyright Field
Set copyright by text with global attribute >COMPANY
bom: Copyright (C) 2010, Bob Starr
